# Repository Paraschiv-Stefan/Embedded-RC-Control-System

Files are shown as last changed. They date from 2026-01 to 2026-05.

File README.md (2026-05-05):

# Electronic Speed Controller (ESC)

Custom 3-phase sensorless BLDC ESC designed for high-performance RC applications.

---

## Schematic

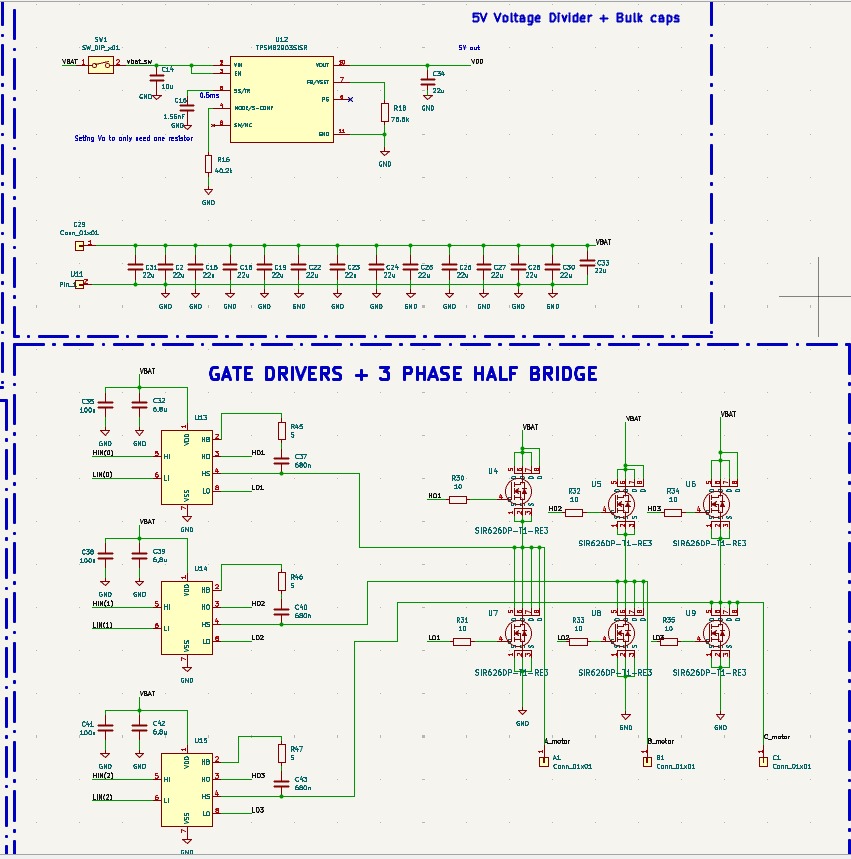
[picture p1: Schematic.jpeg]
Schematic

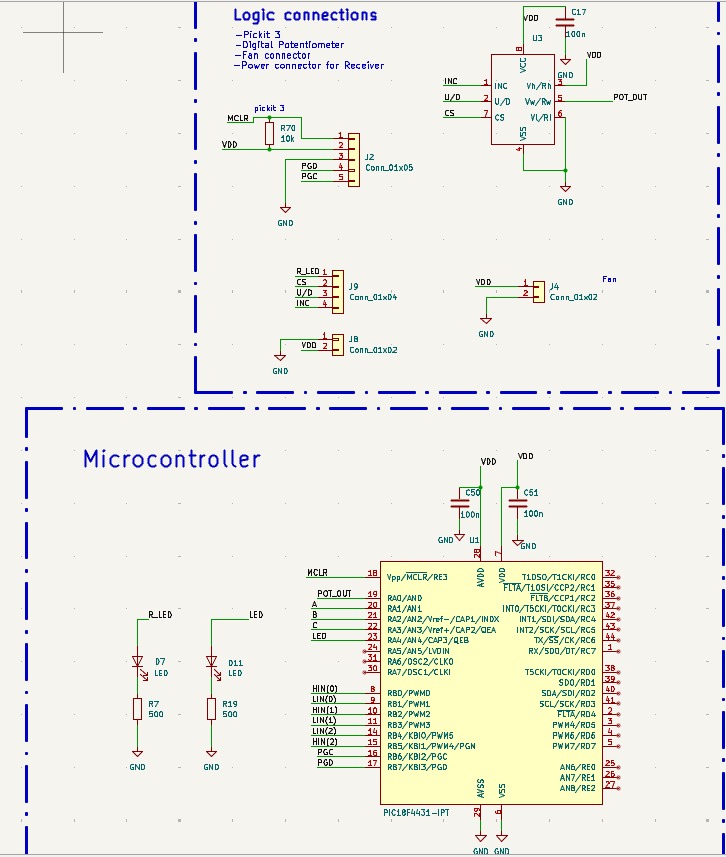
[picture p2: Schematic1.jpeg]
Schematic

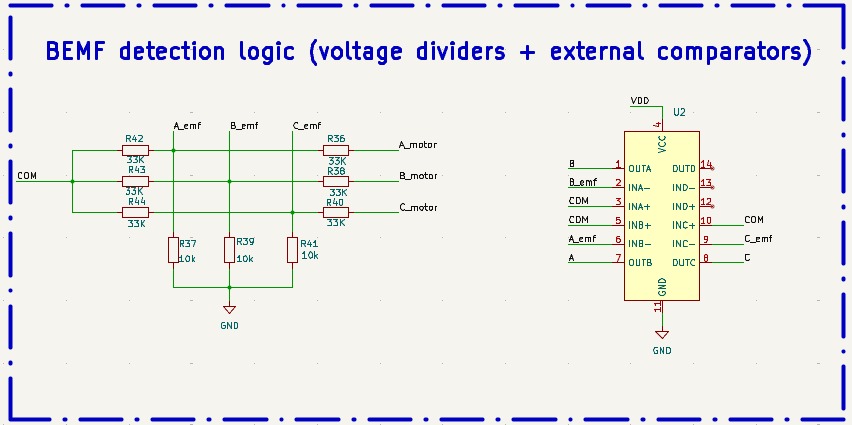
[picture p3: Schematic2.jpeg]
Schematic

> Full system schematic including control logic, power stage, and feedback network.

---

## Overview

This ESC is built around a 50x50 mm **fully custom 6-layer PCB**, designed to handle high current loads while maintaining signal integrity for precise motor control.

It implements **sensorless commutation using BEMF detection**, enabling reliable operation without Hall sensors. The main goal of this ESC was to be as close as possible to what can be found on the market today. With the exception of the control logic using a digital potentiometer instead of PWM signal to drive the motor I can say that I've managed to achieve that.

---

## Hardware Design

### Microcontroller

* **PIC18F4431**
  Dedicated motor control MCU with PWM modules optimized for 3-phase control. At the time of designing the ESC I was clueless regarding which MCU to use. I ended up with an ancient one 😂 which eventually managed to do the job but I would consider far better and far newer options in the future designs

---

### Motor Control & Feedback

* **X9C103 Digital Potentiometer**
  Used for control input

* **MCP6564 (Quad Comparator)**
  Used alongside voltage dividers for **Back-EMF (BEMF) zero-crossing detection**

---

### Power Stage

* **SIR626DP-T1-RE3 MOSFETs**
  Low Rds(on) MOSFETs for high current handling

* **NCV51511 Gate Drivers**
  Bootstrap high/low-side drivers for their compact package and efficient switching

---

### Power Supply

* **TPMS82903 Buck Converter**
* Capable of outputting: **5V | 3A (15W)**
  Powers:

  * Logic circuitry
  * Receiver

---

## PCB Design

* **6-layer PCB**
* Optimized for:

  * Power distribution
  * Thermal performance
  * Compact design

---

## PCB Layers

### Layer 1 (Top)

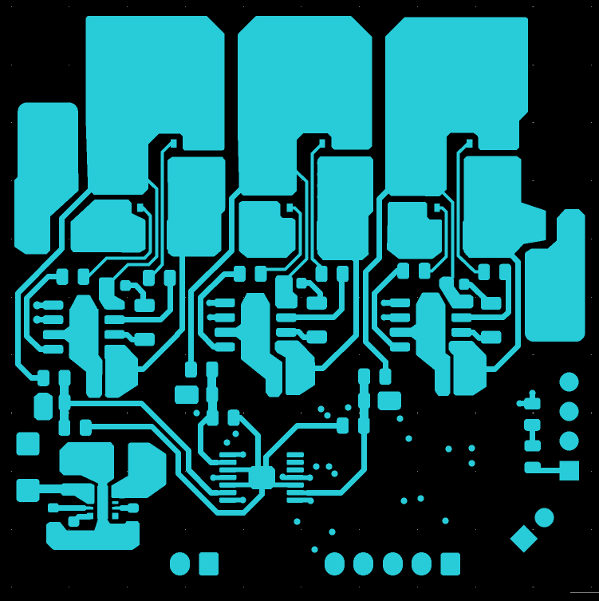
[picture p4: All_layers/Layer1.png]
Layer 1


> The first layer prioritizes clean signal routing, minimizing unnecessary vias to maintain direct, efficient connections between components. The dominant copper polygons on this layer belong to the power phase section, which occupies the upper portion of the board.

### Layer 2

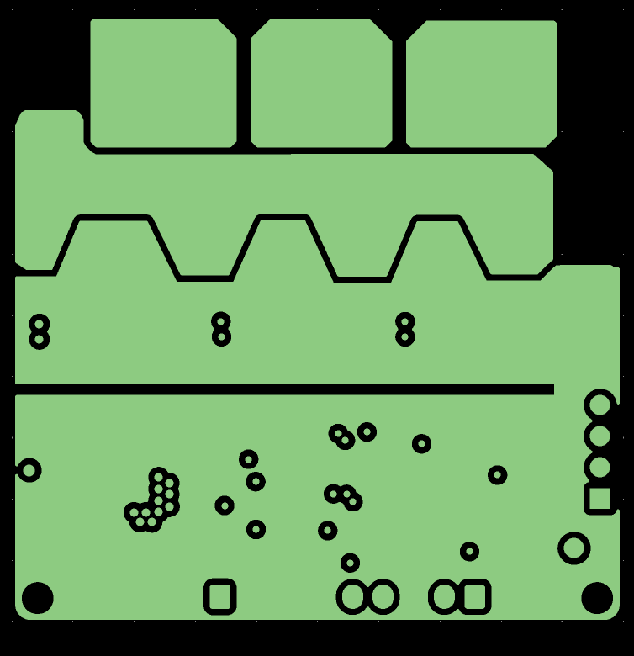
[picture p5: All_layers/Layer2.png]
Layer 2


> From the second layer onward, the focus shifts heavily toward the power stages. A key distinction on this layer is the separation between the power ground and the logic ground planes, keeping the two domains isolated within the board.

### Layer 3

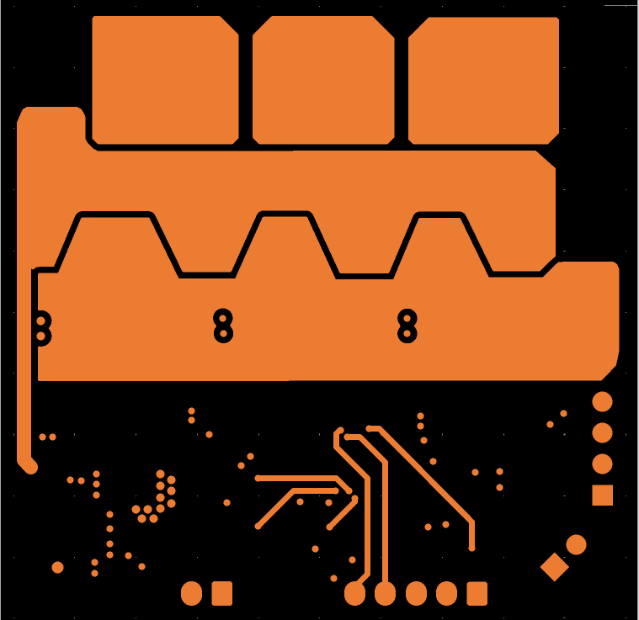
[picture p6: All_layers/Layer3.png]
Layer 3


> This layer mirrors the power structure of layer two, with the exception that the logic ground is absent. Only the traces connecting the comparators to the microcontroller remain, alongside the power supply traces for the buck converter.

### Layer 4

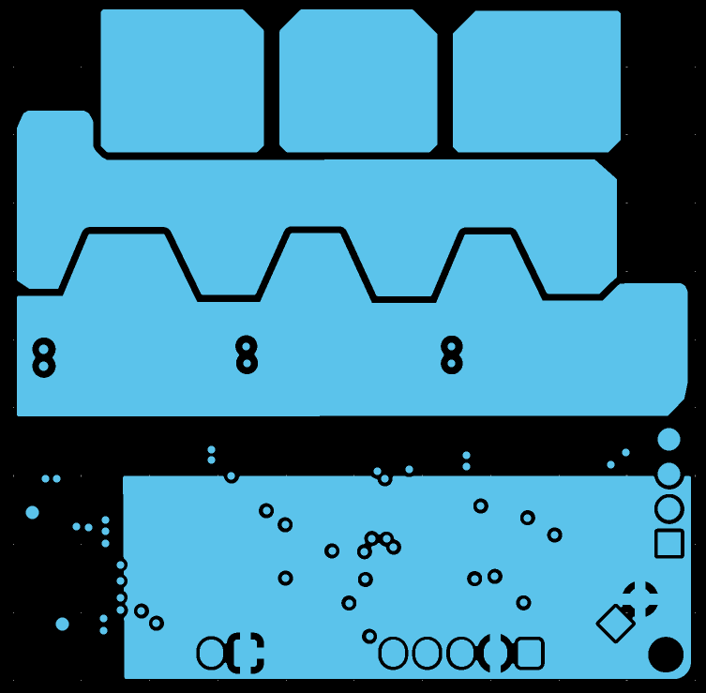
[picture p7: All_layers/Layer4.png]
Layer 4


> The power polygons from the previous layers are carried over here, with the addition of a logic power plane distributed to all relevant components.

### Layer 5

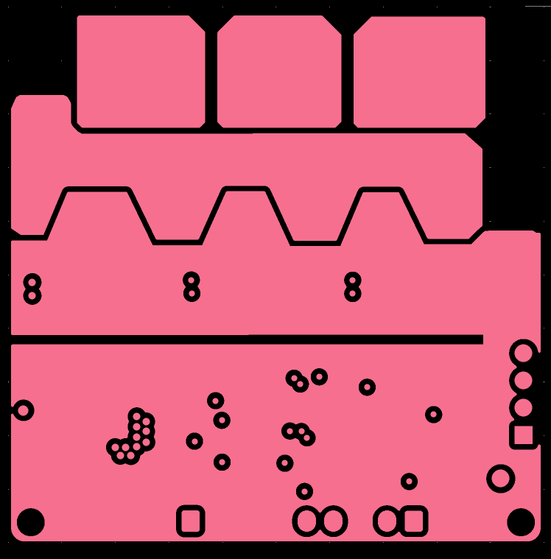
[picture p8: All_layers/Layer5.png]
Layer 5


> An exact replica of layer two.

### Layer 6

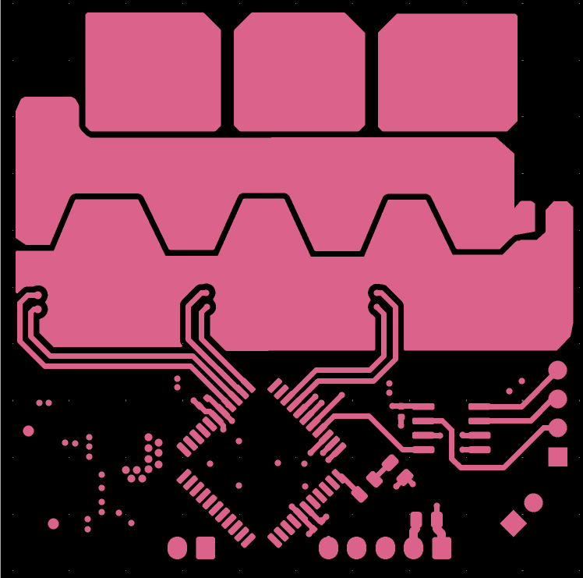
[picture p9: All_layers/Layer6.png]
Layer 6


> The final layer is dedicated primarily to the logic-side components. Given the compact board size (50×50 mm), placing components on the bottom side was necessary to meet density requirements. Also notable on this layer are the PWM traces running from the microcontroller to the gate drivers, which switch the MOSFETs and control the motor. In retrospect, routing these traces on an inner layer would have been preferable — the outer copper thickness is 35 µm compared to 17.5 µm on the inner layers, which leaves the outer power ground polygon with a heavier copper weight than intended. That said, no issues have been observed during testing so far.

---

## Real PCB

### Front

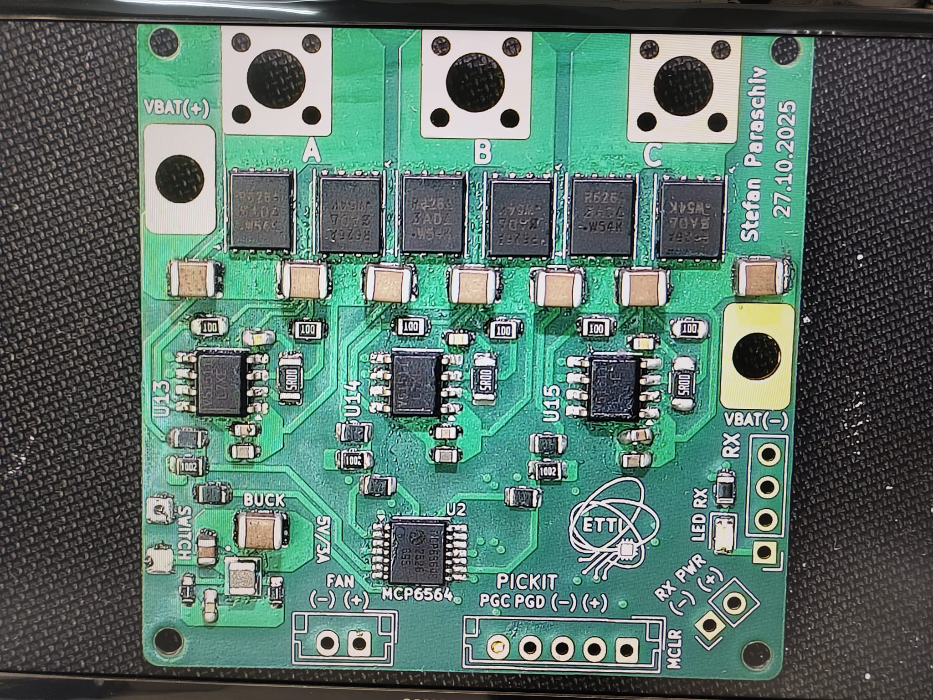
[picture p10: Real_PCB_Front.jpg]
PCB Front


### Back

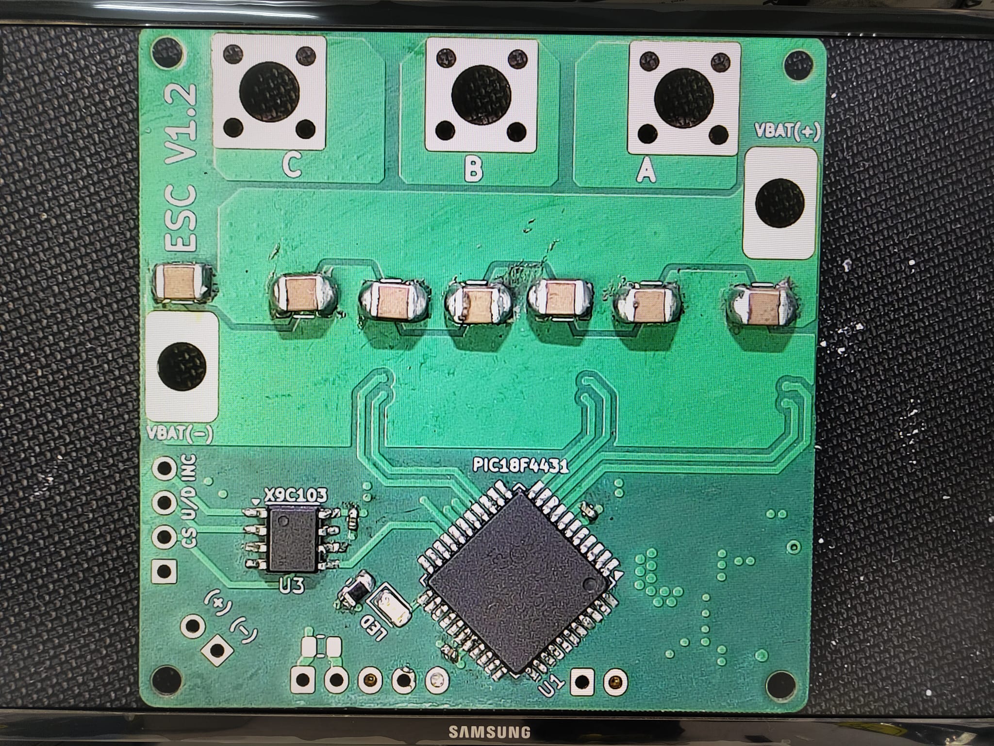
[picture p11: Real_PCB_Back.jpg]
PCB Back


> Final assembled board used for testing and validation.

---

## Firmware

The firmware is adapted from:

* https://github.com/k-omura/SensorlessBLDC_PIC18F1230

Modified to:

* Match this hardware design
* Implement sensorless BLDC control
* Optimize for RC vehicle response

---

## Target BLDC Motor

* **3660 BLDC Motor**
* **4200KV**
* **4 poles**
* **Max RPM:** ~50,000

---

## Notes

* Designed for RC car applications
* Focus on performance and efficiency
* Continuously improved and tested

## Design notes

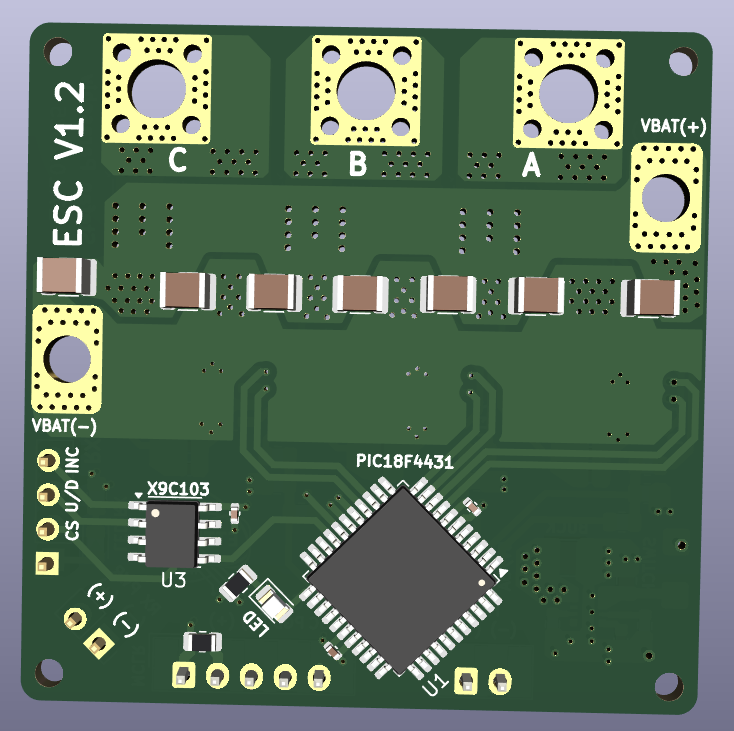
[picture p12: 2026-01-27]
Back_ESC.png

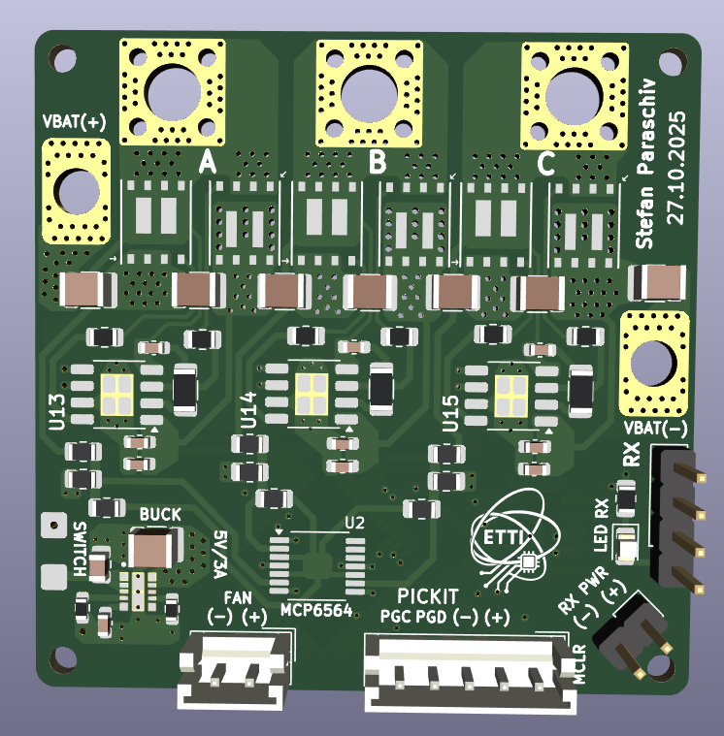
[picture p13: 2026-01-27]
Front_ESC.png

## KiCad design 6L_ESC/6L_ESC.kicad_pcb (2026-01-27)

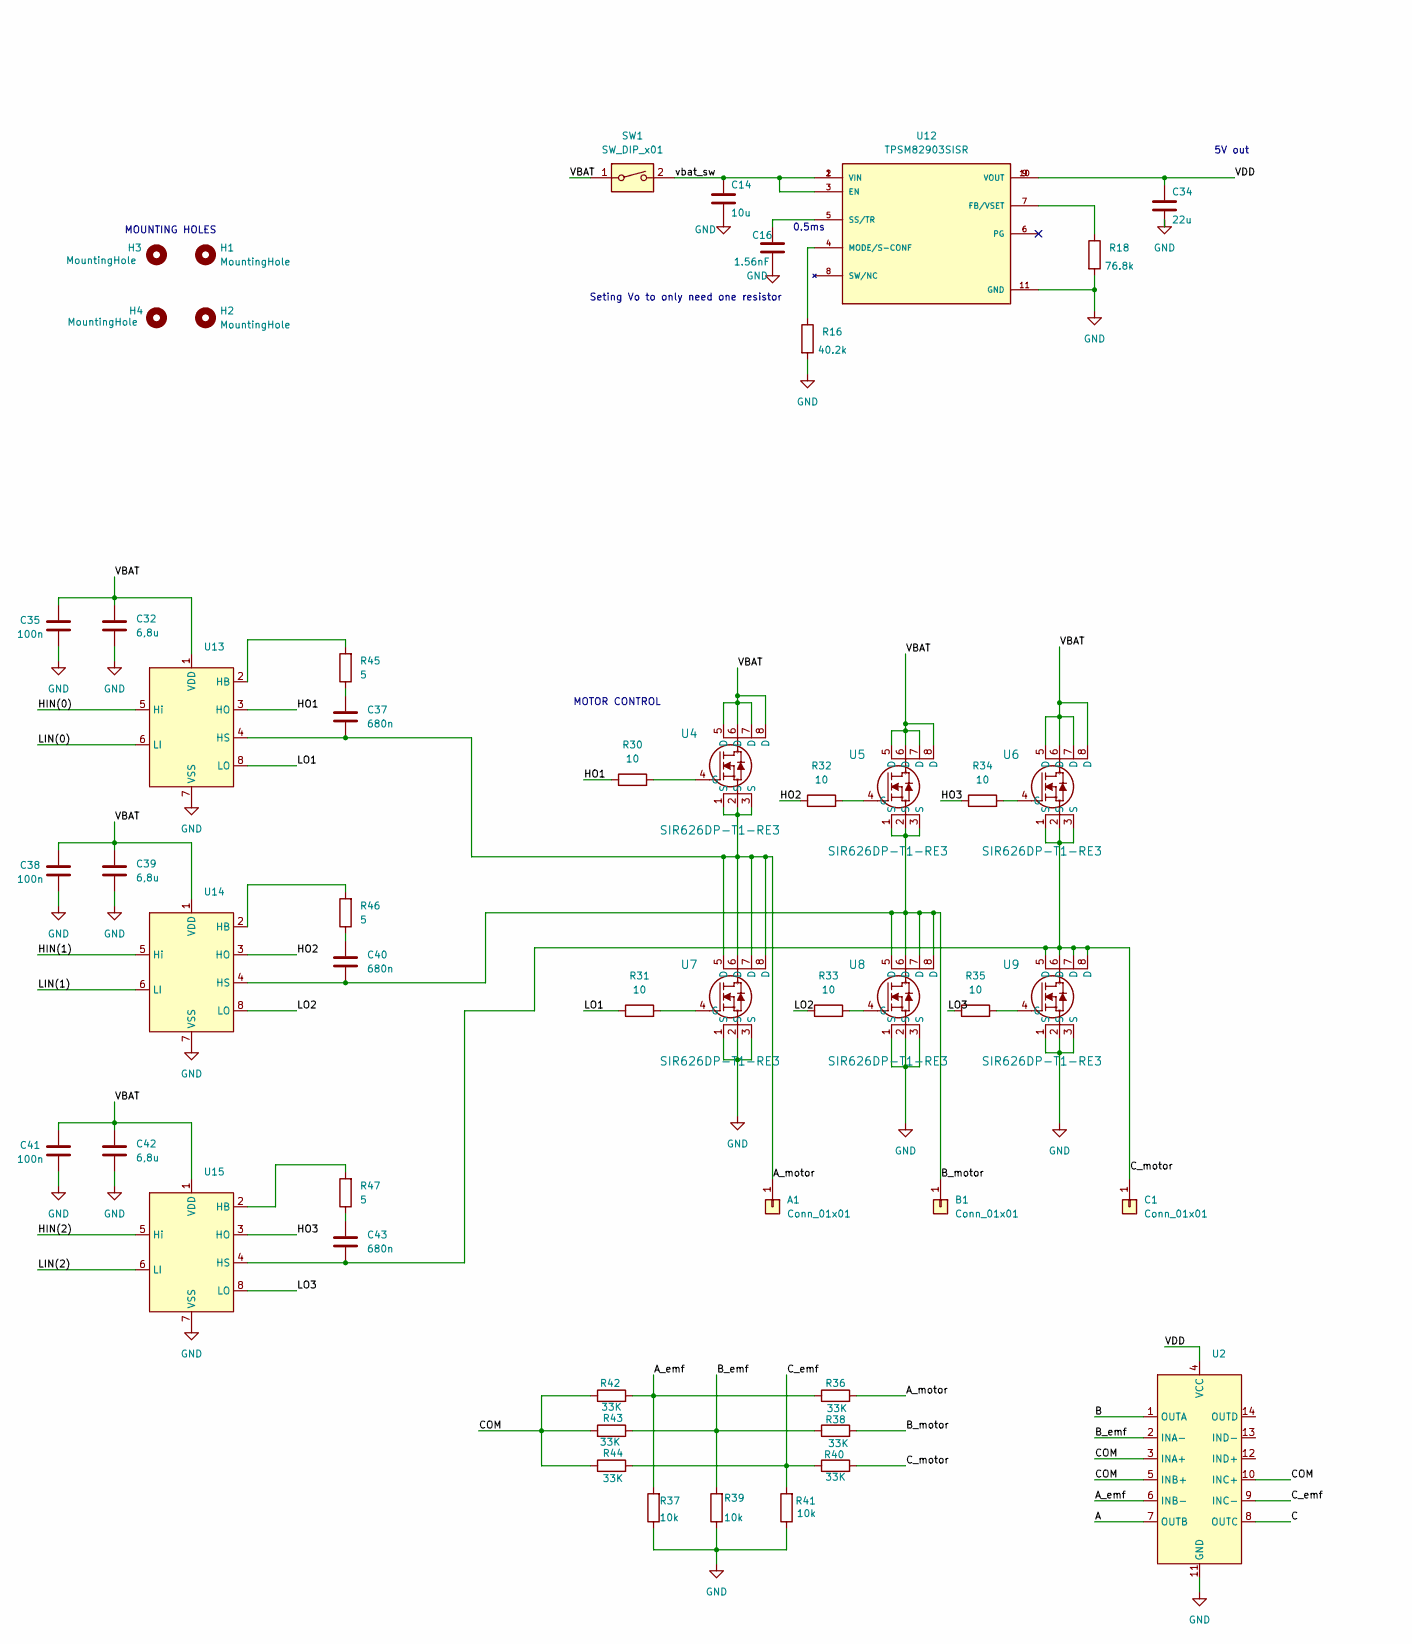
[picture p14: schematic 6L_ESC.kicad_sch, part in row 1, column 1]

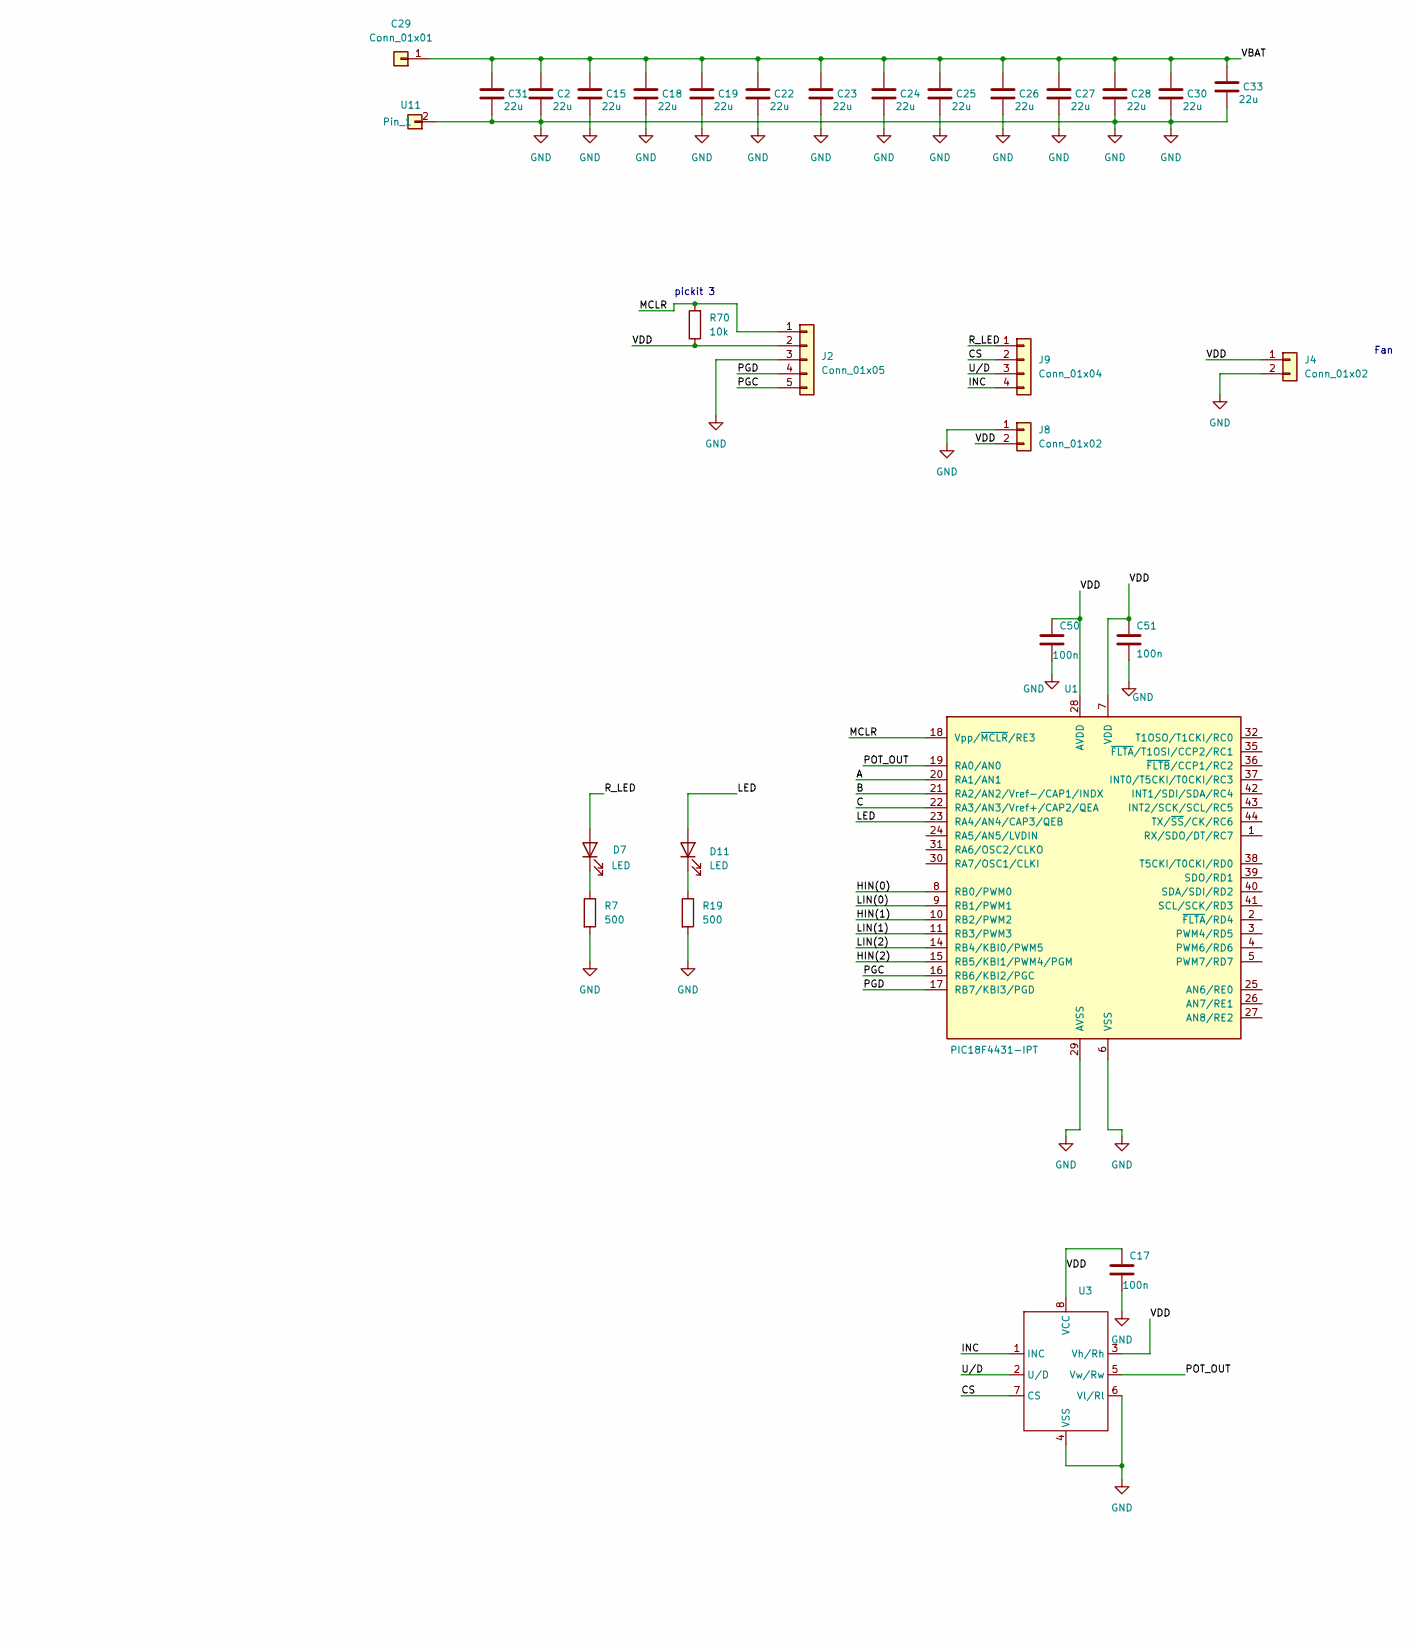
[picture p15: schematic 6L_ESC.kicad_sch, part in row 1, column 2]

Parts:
A1: Conn_01x01; PHASE_PAD
B1: Conn_01x01; PHASE_PAD
C1: Conn_01x01; PHASE_PAD
C2, C15, C18, C19, C22, C23, C24, C25, C26, C27, C28, C30, C31, C33, C34: 22u; C_1210_3225Metric
C14: 10u; C_0805_2012Metric
C16: 1.56nF; C_0603_1608Metric
C17, C50, C51: 100n; C_0402_1005Metric
C29: Conn_01x01; BAT+
C32, C39, C42: 6,8u; C_0603_1608Metric
C35, C38, C41: 100n; C_0603_1608Metric
C37, C40, C43: 680n; C_0603_1608Metric
D7, D11: LED; LED_0805_2012Metric
H1, H2, H3, H4: MountingHole; MountingHole_2.1mm
J2: Conn_01x05; JST_EH_B5B-EH-A_1x05_P2.50mm_Vertical
J4: Conn_01x02; JST_EH_B2B-EH-A_1x02_P2.50mm_Vertical
J8: Conn_01x02; PinHeader_1x02_P2.54mm_Vertical
J9: Conn_01x04; PinHeader_1x04_P2.54mm_Vertical
R7, R19: 500; R_0805_2012Metric
R16: 40.2k; R_0603_1608Metric
R18: 76.8k; R_0603_1608Metric
R30, R31, R32, R33, R34, R35: 10; R_0805_2012Metric
R36, R38, R40, R42, R43, R44: 33K; R_0805_2012Metric
R37, R39, R41, R70: 10k; R_0805_2012Metric
R45, R46, R47: 5; R_1206_3216Metric
SW1: SW_DIP_x01; switch
U1: PIC18F4431-IPT; TQFP-44_10x10mm_P0.8mm
U2: comp_tssop-14_lm324
U3: SOIC-8_3.9x4.9mm_P1.27mm
U4, U5, U6: SIR626DP-T1-RE3; sir626_redefined
U7, U8, U9: SIR626DP-T1-RE3; sir626_les_holes
U11: BAT-
U12: TPSM82903SISR; IC_TPSM82903SISR; PARTREV B; DigiKey_Part_Number 296-TPSM82903SISRCT-ND
U13, U14, U15: NVC51511

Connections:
/A: U1.20 (RA1/AN1), U2.7 (OUTB)
/A_emf: R36.1, R37.2, R42.2, U2.6 (INB-)
/A_motor: A1.1, C37.2, R36.2, U4.1 (S), U4.2 (S), U4.3 (S), U7.5 (D), U7.6 (D), U7.7 (D), U7.8 (D), U13.4 (HS)
/B: U1.21 (RA2/AN2/Vref-/CAP1/INDX), U2.1 (OUTA)
/B_emf: R38.1, R39.2, R43.1, U2.2 (INA-)
/B_motor: B1.1, C40.2, R38.2, U5.1 (S), U5.2 (S), U5.3 (S), U8.5 (D), U8.6 (D), U8.7 (D), U8.8 (D), U14.4 (HS)
/C: U1.22 (RA3/AN3/Vref+/CAP2/QEA), U2.8 (OUTC)
/COM: R42.1, R43.2, R44.1, U2.3 (INA+), U2.5 (INB+), U2.10 (INC+)
/CS: J9.2, U3.7 (CS)
/C_emf: R40.1, R41.2, R44.2, U2.9 (INC-)
/C_motor: C1.1, C43.2, R40.2, U6.1 (S), U6.2 (S), U6.3 (S), U9.5 (D), U9.6 (D), U9.7 (D), U9.8 (D), U15.4 (HS)
/HIN(0): U1.8 (RB0/PWM0), U13.5 (Hi)
/HIN(1): U1.10 (RB2/PWM2), U14.5 (Hi)
/HIN(2): U1.15 (RB5/KBI1/PWM4/PGM), U15.5 (Hi)
/HO1: R30.1, U13.3 (HO)
/HO2: R32.1, U14.3 (HO)
/HO3: R34.1, U15.3 (HO)
/INC: J9.4, U3.1 (INC)
/LED: D11.2 (A), U1.23 (RA4/AN4/CAP3/QEB)
/LIN(0): U1.9 (RB1/PWM1), U13.6 (LI)
/LIN(1): U1.11 (RB3/PWM3), U14.6 (LI)
/LIN(2): U1.14 (RB4/KBI0/PWM5), U15.6 (LI)
/LO1: R31.1, U13.8 (LO)
/LO2: R33.1, U14.8 (LO)
/LO3: R35.1, U15.8 (LO)
/MCLR: J2.1, R70.2, U1.18 (Vpp/~MCLR/RE3)
/PGC: J2.5, U1.16 (RB6/KBI2/PGC)
/PGD: J2.4, U1.17 (RB7/KBI3/PGD)
/POT_OUT: U1.19 (RA0/AN0), U3.5 (Vw/Rw)
/R_LED: D7.2 (A), J9.1
/U/D: J9.3, U3.2 (U/D)
/VBAT: C2.1, C15.1, C18.1, C19.1, C22.1, C23.1, C24.1, C25.1, C26.1, C27.1, C28.1, C29.1, C30.1, C31.1, C32.1, C33.1, C35.1, C38.1, C39.1, C41.1, C42.1, SW1.1, U4.5 (D), U4.6 (D), U4.7 (D), U4.8 (D), U5.5 (D), U5.6 (D), U5.7 (D), U5.8 (D), U6.5 (D), U6.6 (D), U6.7 (D), U6.8 (D), U13.1 (VDD), U14.1 (VDD), U15.1 (VDD)
/VDD: C17.1, C34.1, C50.1, C51.1, J2.2, J4.1, J8.2, R70.1, U1.7 (VDD), U1.28 (AVDD), U2.4 (VCC), U3.3 (Vh/Rh), U3.8 (VCC), U12.9 (VOUT), U12.10 (VOUT)
/vbat_sw: C14.1, SW1.2, U12.1 (VIN), U12.2 (VIN), U12.3 (EN)
GND: C2.2, C14.2, C15.2, C16.2, C17.2, C18.2, C19.2, C22.2, C23.2, C24.2, C25.2, C26.2, C27.2, C28.2, C30.2, C31.2, C32.2, C33.2, C34.2, C35.2, C38.2, C39.2, C41.2, C42.2, C50.2, C51.2, J2.3, J4.2, J8.1, R7.2, R16.2, R18.2, R19.2, R37.1, R39.1, R41.1, U1.6 (VSS), U1.29 (AVSS), U2.11 (GND), U3.4 (VSS), U3.6 (Vl/Rl), U7.1 (S), U7.2 (S), U7.3 (S), U8.1 (S), U8.2 (S), U8.3 (S), U9.1 (S), U9.2 (S), U9.3 (S), U11.2 (Pin_1), U12.11 (GND), U13.7 (VSS), U14.7 (VSS), U15.7 (VSS)
unnamed: C37.1, R45.1
unnamed: C40.1, R46.1
unnamed: C43.1, R47.1
unnamed: D7.1 (K), R7.1
unnamed: D11.1 (K), R19.1
unnamed: R30.2, U4.4 (G)
unnamed: R32.2, U5.4 (G)
unnamed: R34.2, U6.4 (G)
unnamed: R31.2, U7.4 (G)
unnamed: R33.2, U8.4 (G)
unnamed: R35.2, U9.4 (G)
unnamed: R18.1, U12.7 (FB/VSET)
unnamed: R16.1, U12.4 (MODE/S-CONF)
unnamed: C16.1, U12.5 (SS/TR)
unnamed: R45.2, U13.2 (HB)
unnamed: R46.2, U14.2 (HB)
unnamed: R47.2, U15.2 (HB)

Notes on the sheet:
Seting Vo to only need one resistor
Fan
MOTOR CONTROL
MOUNTING HOLES
0.5ms
pickit 3
5V out

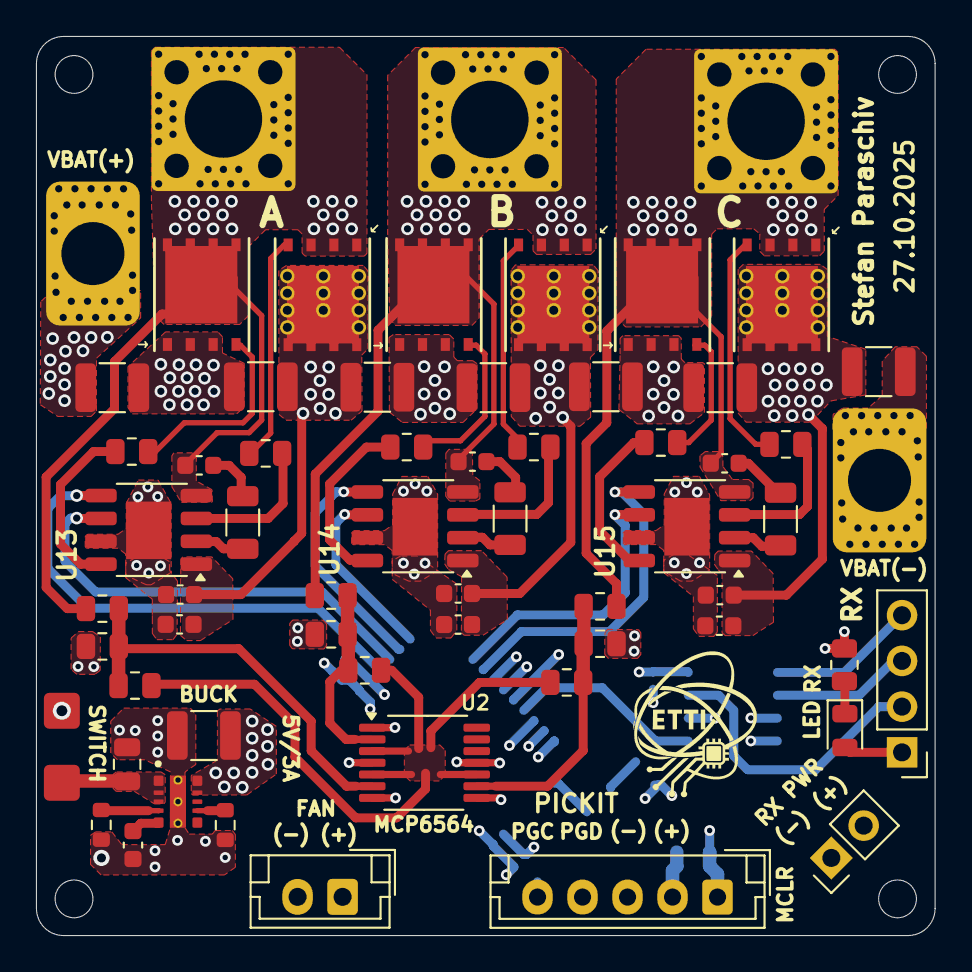
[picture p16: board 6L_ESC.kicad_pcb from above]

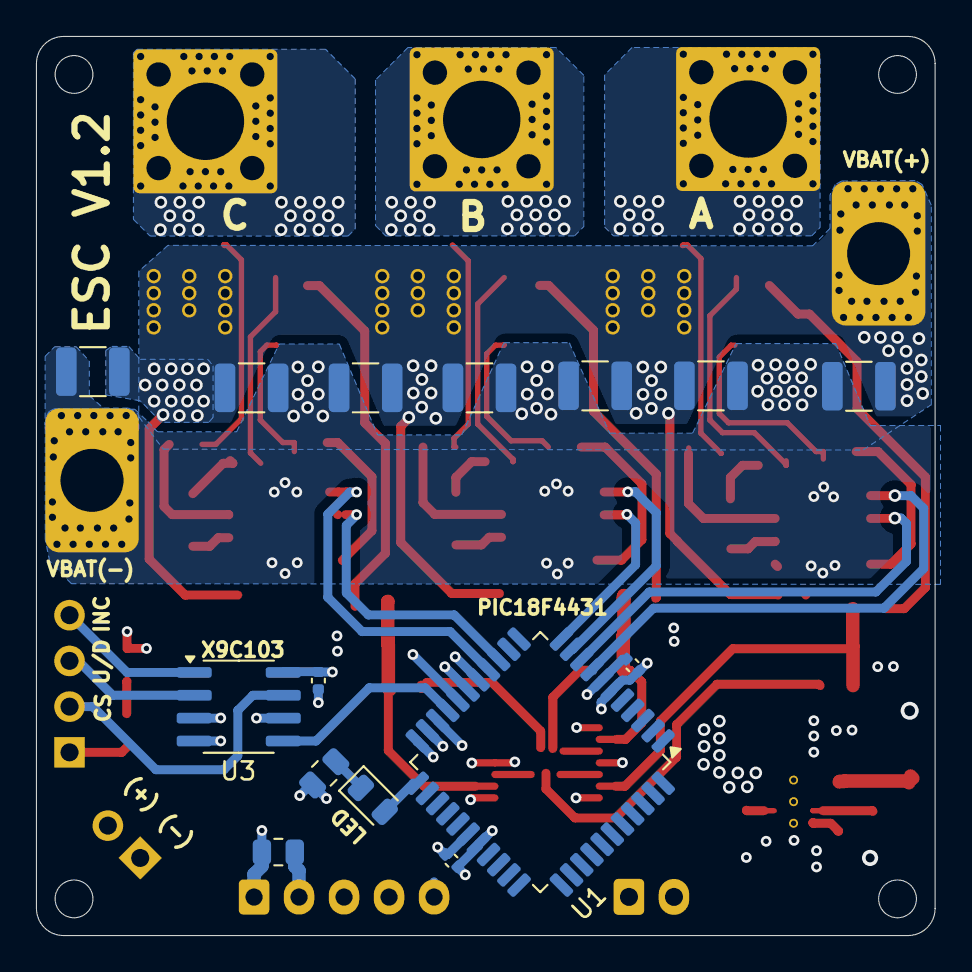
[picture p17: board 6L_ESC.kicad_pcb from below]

Board: 6 copper layers, 49.9 x 49.9 mm, 81 parts (15 on the bottom side), 52 nets.
